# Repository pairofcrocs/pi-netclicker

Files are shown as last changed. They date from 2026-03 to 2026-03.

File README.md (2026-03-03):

# Pi NetClicker

A wireless, battery-powered button device that sends real mouse click events to a Windows PC over a network. Press a physical button on the handheld device — the PC receives a left mouse down/up event instantly.

Communication runs over [Tailscale](https://tailscale.com), so it works across any network without port forwarding.

---

## How It Works

```
[Physical Button] → [Pi Zero 2 W] → Tailscale VPN → [Windows PC] → Mouse Click
```

- `button_client.py` runs on the Pi. It monitors the button via GPIO interrupt and sends `DOWN`/`UP` events over TCP to the Windows machine.
- `windows.py` runs on Windows. It receives those events and simulates real left mouse button presses using `pynput`.
- `ap_server.py` runs on the Pi and creates a Wi-Fi hotspot that lets you add or change network credentials from any phone or laptop. It's triggered on demand by a double-press of the PiSugar2's built-in button — no SSH or keyboard required.

---

## Parts List

| Part | Link |
|---|---|
| Raspberry Pi Zero 2 W | [Amazon](https://www.amazon.com/dp/B09LH5SBPS) |
| PiSugar2 (battery board) | [Amazon](https://www.amazon.com/dp/B08D678XPR) |
| 2200mAh extended battery | [Amazon](https://www.amazon.com/dp/B0CTQ6VBB6) |
| Momentary push button | [Amazon](https://www.amazon.com/dp/B09V2L86DR) |
| 3D printed case | `case.stl` + `lid.stl` (in this repo) |

---

## 3D Printed Case

Four STL files are included:

| File | Qty | Description |
|---|-----|---|
| `case.stl` | 1 | Main enclosure body |
| `lid.stl` | 2 | Top and bottom lids — print twice and glue to seal |
| `button.stl` | 1 | Button cap that sits over the momentary push button |
| `switch.stl` | 1 | Switch actuator/cover |

After assembling the electronics inside, glue both lids in place to seal the enclosure.

> **Note:** The 3D printed case is the weakest part of this build. It can crack under hard drops. The electronics inside are fine — reprint and reassemble if needed.

Any FDM printer works. No specific settings required.

---

## Hardware Assembly

### Wiring the Button

The button connects directly to the Pi's GPIO header — no resistors needed (internal pull-up is enabled in firmware).

| Button leg | Pi Zero 2 W pin |
|---|---|
| Leg 1 | GPIO 17 (physical pin 11) |
| Leg 2 | GND (physical pin 9) |

### Attaching the PiSugar2

The PiSugar2 attaches to the back of the Pi Zero 2 W via spring-loaded pogo pins — no soldering required. Align the board, press it on, and secure it with the included screws.

### Installing the 2200mAh Battery

The PiSugar2 ships with a smaller default battery. To use the 2200mAh extended battery:

1. Carefully disconnect the default battery's JST connector from the PiSugar2 board.
2. Connect the 2200mAh battery's JST connector in its place.
3. After booting (see software setup), open the PiSugar2 web interface at `http://<pi-ip>:8421`.
4. Navigate to **Settings** and set the battery capacity to **2200 mAh** so the percentage display is accurate.

### Configuring the PiSugar2 Button (Wi-Fi Provisioning)

The PiSugar2 has its own physical button. Configure a double-press to trigger `ap_server.py` so you can change Wi-Fi credentials at any time without SSH:

1. Open the PiSugar2 web interface at `http://<pi-ip>:8421`
2. Go to **Settings → Button**
3. Set the **Double Tap** action to **Custom** and enter:
   ```
   sudo python3 /home/<your-username>/ap_server.py
   ```
4. Save the setting

From that point on, a double-press of the PiSugar2 button will bring up the `NetClicker` hotspot so you can reconfigure Wi-Fi without touching a terminal.

---

## Software Setup

### 1. Flash the Pi

Use [Raspberry Pi Imager](https://www.raspberrypi.com/software/) to flash **Raspberry Pi OS Lite (64-bit)** to a microSD card.

In the Imager's advanced settings (gear icon), configure:
- Hostname (e.g. `netclicker`)
- Enable SSH
- Set a username/password
- Optionally pre-configure your Wi-Fi here (skips the `ap_server.py` step)

### 2. Wi-Fi Setup via ap_server.py

`ap_server.py` creates a temporary Wi-Fi hotspot called **`NetClicker`** so you can add or change network credentials from any phone or laptop. It's used for both initial setup and changing networks later.

First, install NetworkManager on the Pi:

```bash
sudo apt update && sudo apt install -y network-manager python3
sudo systemctl stop wpa_supplicant
sudo systemctl disable wpa_supplicant
```

Copy `ap_server.py` to the Pi, then run it:

```bash
sudo python3 ap_server.py
```

Or, after completing the PiSugar2 button setup below, simply **double-press the PiSugar2 button** to start it automatically.

**To connect and configure:**

1. On your phone or laptop, connect to Wi-Fi network **`NetClicker`** (password: `netclicker`)
2. Open a browser and go to `http://10.42.0.1:8080`
3. Select your network and enter the password
4. Click **Add Connection** — the Pi saves the credentials and reboots

### 3. Install Tailscale on the Pi

SSH into the Pi after it connects to your network:

```bash
curl -fsSL https://tailscale.com/install.sh | sh
sudo tailscale up
```

Follow the authentication link printed in the terminal. Once authenticated, note the Pi's Tailscale IP:

```bash
tailscale ip -4
```

### 4. Install Tailscale on Windows

Download and install Tailscale from [tailscale.com/download](https://tailscale.com/download). Sign in with the same account used on the Pi. Both devices should appear in your Tailscale admin panel.

### 5. Configure the Client

On the Pi, edit `button_client.py` and update `WINDOWS_IP` with your Windows machine's Tailscale IP address:

```python
WINDOWS_IP = '100.x.x.x'  # your Windows Tailscale IP
```

Find your Windows Tailscale IP in the Tailscale system tray icon or at [login.tailscale.com](https://login.tailscale.com).

### 6. Install Pi Dependencies

```bash
pip3 install RPi.GPIO
```

> `RPi.GPIO` may already be installed on Raspberry Pi OS. If the script runs without error, you're good.

### 7. Auto-Start on Boot (systemd service)

Create a service file so `button_client.py` starts automatically when the Pi powers on:

```bash
sudo nano /etc/systemd/system/netclicker.service
```

Paste the following (adjust the path if you placed the script elsewhere):

```ini
[Unit]
Description=NetClicker Button Client
After=network-online.target tailscaled.service
Wants=network-online.target

[Service]
ExecStart=/usr/bin/python3 /home/<your-username>/button_client.py
Restart=always
RestartSec=5
User=<your-username>

[Install]
WantedBy=multi-user.target
```

Enable and start it:

```bash
sudo systemctl daemon-reload
sudo systemctl enable netclicker
sudo systemctl start netclicker
```

Check it's running:

```bash
sudo systemctl status netclicker
```

From this point on, powering on the device will automatically connect to the Windows server.

---

## Windows Setup

### Install Dependencies

```bash
pip install pynput sv-ttk
pip install py-window-styles  # optional: dark title bar on Windows 11
```

### Run the Server

```bash
python windows.py
```

The GUI will appear and the server starts automatically on port `5000`. When the Pi connects, the status indicator turns green. Press the physical button — you'll see the click events in the log (enable "Log click events" checkbox to see each DOWN/UP).

### Features

- **Log click events:** Toggle logging of individual DOWN/UP events in the Options panel. Off by default to keep the log clean at high click rates.

---

## File Reference

| File | Runs on | Purpose |
|---|---|---|
| `button_client.py` | Raspberry Pi | Reads button, sends events over TCP |
| `windows.py` | Windows PC | Receives events, simulates mouse clicks |
| `ap_server.py` | Raspberry Pi | One-time Wi-Fi provisioning hotspot |
| `case.stl` | — | 3D printable enclosure body |
| `lid.stl` | — | 3D printable lid (print twice) |
| `button.stl` | — | 3D printable button cap |
| `switch.stl` | — | 3D printable switch actuator |

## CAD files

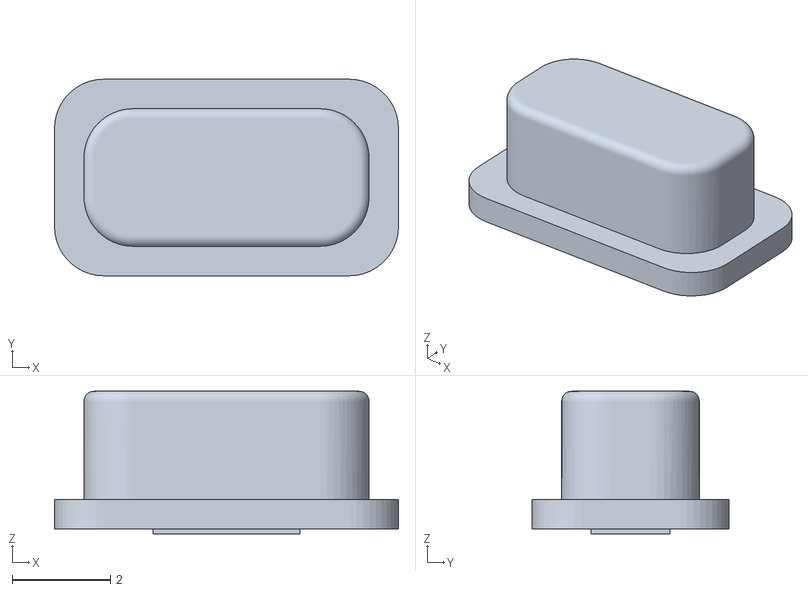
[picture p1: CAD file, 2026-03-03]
button.stl
7.00 x 4.00 x 2.90

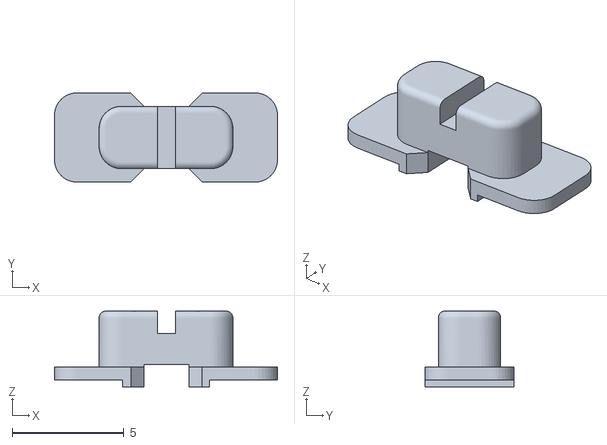
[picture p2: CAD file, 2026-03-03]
switch.stl
10.0 x 4.00 x 3.40

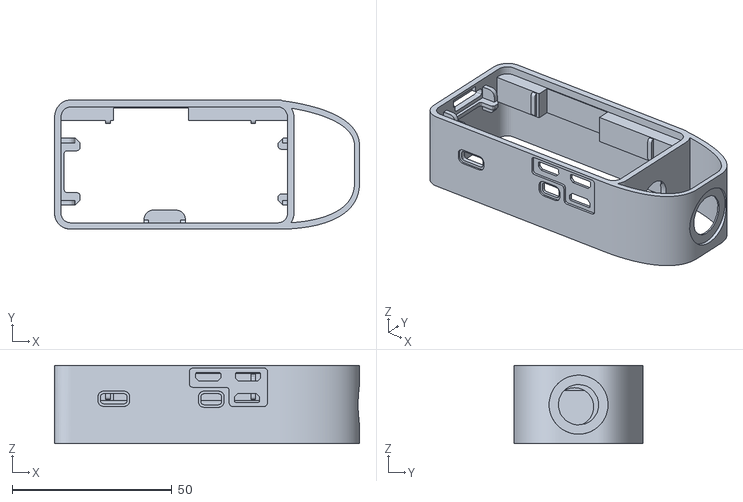
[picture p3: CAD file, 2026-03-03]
case.stl
95.5 x 40.5 x 24.5

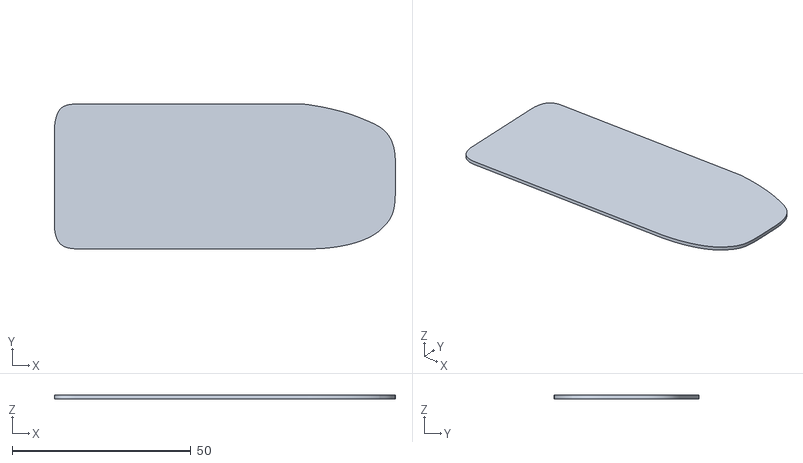
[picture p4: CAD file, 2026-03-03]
lid.stl
95.5 x 40.5 x 1.00

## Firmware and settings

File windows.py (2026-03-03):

#!/usr/bin/env python3
"""
Windows Click Server - GUI Version with Sun Valley Theme
Receives button events from Pi and simulates mouse clicks

IMPROVEMENTS:
- Better socket cleanup and handling
- Faster detection of dead connections
- TCP keepalive for detecting network changes
- Non-blocking client handling
"""

import select
import socket
import threading
import sys
import tkinter as tk
from tkinter import ttk
from datetime import datetime
from pynput.mouse import Button, Controller
import sv_ttk

# Optional: py-window-styles for dark title bar on Windows
try:
    import pywinstyles
    _HAS_PYWINSTYLES = True
except Exception:
    _HAS_PYWINSTYLES = False

LISTEN_IP = '0.0.0.0'
PORT = 5000


def apply_theme_to_titlebar(root):
    try:
        if not _HAS_PYWINSTYLES:
            return
        version = sys.getwindowsversion()
        dark_mode = sv_ttk.get_theme() == "dark"
        if version.major == 10 and version.build >= 22000:
            pywinstyles.change_header_color(root, "#1c1c1c" if dark_mode else "#fafafa")
        elif version.major == 10:
            pywinstyles.apply_style(root, "dark" if dark_mode else "normal")
            try:
                root.wm_attributes("-alpha", 0.99)
                root.wm_attributes("-alpha", 1.0)
            except tk.TclError:
                pass
    except Exception:
        pass


class ClickServerGUI:
    def __init__(self, root):
        self.root = root
        self.root.title("Windows Click Server")
        self.root.geometry("700x600")
        self.root.resizable(False, False)

        sv_ttk.set_theme("dark")
        self.root.bind("<Map>", lambda e: apply_theme_to_titlebar(self.root))

        self.server = None
        self.is_running = False
        self.mouse = Controller()
        self.client_connected = False
        
        # Track current client connection
        self.current_client_conn = None
        self.client_lock = threading.Lock()

        # --- Click logging toggle ---
        self.log_clicks_var = tk.BooleanVar(value=False)

        self.setup_ui()
        self.root.after(100, self.start_server)

    # --------------------------------------------------------
    def setup_ui(self):
        main_frame = ttk.Frame(self.root, padding="15")
        main_frame.grid(row=0, column=0, sticky=(tk.W, tk.E, tk.N, tk.S))

        title_label = ttk.Label(main_frame, text="Click Server", font=("Segoe UI", 18, "bold"))
        title_label.grid(row=0, column=0, columnspan=2, pady=(0, 15))

        # Status frame
        status_frame = ttk.LabelFrame(main_frame, text="Status", padding="15")
        status_frame.grid(row=1, column=0, columnspan=2, sticky=(tk.W, tk.E), pady=(0, 15))

        server_frame = ttk.Frame(status_frame)
        server_frame.grid(row=0, column=0, sticky=tk.W, pady=5)
        ttk.Label(server_frame, text="Server:", font=("Segoe UI", 10)).pack(side=tk.LEFT, padx=(0, 10))
        self.server_status = tk.Canvas(server_frame, width=12, height=12, highlightthickness=0, bg="#1c1c1c")
        self.server_status.pack(side=tk.LEFT, padx=(0, 8))
        self.server_indicator = self.server_status.create_oval(2, 2, 10, 10, fill="#6c6c6c", outline="")
        self.server_label = ttk.Label(server_frame, text="Stopped", font=("Segoe UI", 10))
        self.server_label.pack(side=tk.LEFT)

        client_frame = ttk.Frame(status_frame)
        client_frame.grid(row=1, column=0, sticky=tk.W, pady=5)
        ttk.Label(client_frame, text="Client:", font=("Segoe UI", 10)).pack(side=tk.LEFT, padx=(0, 10))
        self.client_status = tk.Canvas(client_frame, width=12, height=12, highlightthickness=0, bg="#1c1c1c")
        self.client_status.pack(side=tk.LEFT, padx=(0, 8))
        self.client_indicator = self.client_status.create_oval(2, 2, 10, 10, fill="#6c6c6c", outline="")
        self.client_label = ttk.Label(client_frame, text="Not Connected", font=("Segoe UI", 10))
        self.client_label.pack(side=tk.LEFT)

        address_frame = ttk.Frame(status_frame)
        address_frame.grid(row=2, column=0, sticky=tk.W, pady=5)
        ttk.Label(address_frame, text="Address:", font=("Segoe UI", 10)).pack(side=tk.LEFT, padx=(0, 10))
        self.address_label = ttk.Label(address_frame, text=f"{LISTEN_IP}:{PORT}", font=("Segoe UI", 10, "bold"), foreground="#0078d4")
        self.address_label.pack(side=tk.LEFT)

        # Buttons
        button_frame = ttk.Frame(main_frame)
        button_frame.grid(row=2, column=0, columnspan=2, pady=(0, 10))
        self.start_btn = ttk.Button(button_frame, text="Start Server", command=self.start_server, width=18)
        self.start_btn.grid(row=0, column=0, padx=5)
        self.stop_btn = ttk.Button(button_frame, text="Stop Server", command=self.stop_server, width=18, state=tk.DISABLED)
        self.stop_btn.grid(row=0, column=1, padx=5)
        self.clear_btn = ttk.Button(button_frame, text="Clear Log", command=self.clear_log, width=18)
        self.clear_btn.grid(row=0, column=2, padx=5)

        # --- Options frame ---
        options_frame = ttk.LabelFrame(main_frame, text="Options", padding="15")
        options_frame.grid(row=3, column=0, columnspan=2, sticky=(tk.W, tk.E), pady=(0, 15))

        self.log_clicks_chk = ttk.Checkbutton(
            options_frame,
            text="Log click events (DOWN/UP)",
            variable=self.log_clicks_var
        )
        self.log_clicks_chk.grid(row=0, column=0, sticky=tk.W)

        # Log frame
        log_frame = ttk.LabelFrame(main_frame, text="Activity Log", padding="15")
        log_frame.grid(row=4, column=0, columnspan=2, sticky=(tk.W, tk.E, tk.N, tk.S))
        log_frame.columnconfigure(0, weight=1)
        log_frame.rowconfigure(0, weight=1)
        self.log_text = tk.Text(
            log_frame, height=16, width=80, wrap=tk.WORD, font=("Consolas", 9),
            bg="#1e1e1e", fg="#d4d4d4", insertbackground="white",
            borderwidth=0, highlightthickness=0
        )
        self.log_scrollbar = ttk.Scrollbar(log_frame, orient="vertical", command=self.log_text.yview)
        self.log_text.configure(yscrollcommand=self.log_scrollbar.set)
        self.log_text.grid(row=0, column=0, sticky="nsew")
        self.log_scrollbar.grid(row=0, column=1, sticky="ns")

        self.log_text.tag_config("info", foreground="#d4d4d4")
        self.log_text.tag_config("success", foreground="#4ec9b0")
        self.log_text.tag_config("warning", foreground="#ce9178")
        self.log_text.tag_config("error", foreground="#f48771")
        self.log_text.tag_config("timestamp", foreground="#858585")

        self.root.columnconfigure(0, weight=1)
        self.root.rowconfigure(0, weight=1)
        main_frame.columnconfigure(0, weight=1)
        main_frame.rowconfigure(4, weight=1)

        if not _HAS_PYWINSTYLES:
            self.root.after(300, lambda: self.log(
                "Tip: Install 'py-window-styles' for dark title bar on Windows: pip install py-window-styles",
                "warning"
            ))

    def log(self, message, tag="info"):
        timestamp = datetime.now().strftime("%H:%M:%S")
        self.log_text.config(state=tk.NORMAL)
        self.log_text.insert(tk.END, f"[{timestamp}] ", "timestamp")
        self.log_text.insert(tk.END, f"{message}\n", tag)
        self.log_text.see(tk.END)
        self.log_text.config(state=tk.DISABLED)

    def clear_log(self):
        self.log_text.config(state=tk.NORMAL)
        self.log_text.delete(1.0, tk.END)
        self.log_text.config(state=tk.DISABLED)

    def update_server_status(self, running):
        if running:
            self.server_status.itemconfig(self.server_indicator, fill="#4ec9b0")
            self.server_label.config(text="Running")
            self.start_btn.config(state=tk.DISABLED)
            self.stop_btn.config(state=tk.NORMAL)
        else:
            self.server_status.itemconfig(self.server_indicator, fill="#6c6c6c")
            self.server_label.config(text="Stopped")
            self.start_btn.config(state=tk.NORMAL)
            self.stop_btn.config(state=tk.DISABLED)

    def update_client_status(self, connected, addr=None):
        self.client_connected = connected
        if connected:
            self.client_status.itemconfig(self.client_indicator, fill="#4ec9b0")
            self.client_label.config(text=f"Connected: {addr}")
        else:
            self.client_status.itemconfig(self.client_indicator, fill="#6c6c6c")
            self.client_label.config(text="Not Connected")

    def disconnect_current_client(self):
        """Safely disconnect the current client"""
        with self.client_lock:
            if self.current_client_conn:
                try:
                    self.current_client_conn.shutdown(socket.SHUT_RDWR)
                except:
                    pass
                try:
                    self.current_client_conn.close()
                except:
                    pass
                self.current_client_conn = None

    def handle_client(self, conn, addr):
        # Store the current connection
        with self.client_lock:
            # Disconnect any existing client first
            if self.current_client_conn:
                try:
                    self.current_client_conn.shutdown(socket.SHUT_RDWR)
                    self.current_client_conn.close()
                except:
                    pass
            self.current_client_conn = conn
        
        self.root.after(0, lambda: self.update_client_status(True, addr))
        self.root.after(0, lambda: self.log(f"Client connected from {addr}", "success"))
        
        buffer = ""

        try:
            while self.is_running:
                ready, _, _ = select.select([conn], [], [], 0.5)
                if not ready:
                    continue
                try:
                    data = conn.recv(1024)
                    if not data:
                        self.root.after(0, lambda: self.log("Client disconnected (clean)", "warning"))
                        break

                    buffer += data.decode()
                    while '\n' in buffer:
                        message, buffer = buffer.split('\n', 1)
                        message = message.strip()
                        if message == "DOWN":
                            self.mouse.press(Button.left)
                            if self.log_clicks_var.get():
                                self.root.after(0, lambda: self.log("Mouse DOWN", "info"))
                        elif message == "UP":
                            self.mouse.release(Button.left)
                            if self.log_clicks_var.get():
                                self.root.after(0, lambda: self.log("Mouse UP", "info"))
                except Exception as e:
                    self.root.after(0, lambda e=e: self.log(f"Client error: {e}", "error"))
                    break
        except Exception as e:
            self.root.after(0, lambda e=e: self.log(f"Error: {e}", "error"))
        finally:
            with self.client_lock:
                if self.current_client_conn == conn:
                    self.current_client_conn = None
            
            try:
                conn.shutdown(socket.SHUT_RDWR)
            except:
                pass
            try:
                conn.close()
            except:
                pass
            
            self.root.after(0, lambda: self.update_client_status(False))
            self.root.after(0, lambda: self.log("Connection closed", "info"))

    def server_thread(self):
        self.server = socket.socket(socket.AF_INET, socket.SOCK_STREAM)
        self.server.setsockopt(socket.SOL_SOCKET, socket.SO_REUSEADDR, 1)
        self.server.setsockopt(socket.SOL_SOCKET, socket.SO_KEEPALIVE, 1)
        
        # Enable TCP keepalive to detect dead connections faster
        if sys.platform == 'win32':
            # Windows: (on/off, time, interval)
            self.server.ioctl(socket.SIO_KEEPALIVE_VALS, (1, 10000, 3000))
        
        try:
            self.server.bind((LISTEN_IP, PORT))
            self.server.listen(1)
            self.server.settimeout(1.0)
            self.root.after(0, lambda: self.log(f"Server listening on {LISTEN_IP}:{PORT}", "success"))
            self.root.after(0, lambda: self.log("Waiting for Pi to connect...", "info"))
            
            while self.is_running:
                try:
                    conn, addr = self.server.accept()
                    
                    # Configure the client socket with keepalive
                    conn.setsockopt(socket.SOL_SOCKET, socket.SO_KEEPALIVE, 1)
                    if sys.platform == 'win32':
                        conn.ioctl(socket.SIO_KEEPALIVE_VALS, (1, 10000, 3000))
                    
                    # Handle client in a separate thread so we can continue accepting
                    client_thread = threading.Thread(
                        target=self.handle_client, 
                        args=(conn, addr), 
                        daemon=True
                    )
                    client_thread.start()
                    
                except socket.timeout:
                    continue
                except Exception as e:
                    if self.is_running:
                        self.root.after(0, lambda e=e: self.log(f"Accept error: {e}", "error"))
        except Exception as e:
            self.root.after(0, lambda e=e: self.log(f"Server error: {e}", "error"))
        finally:
            self.server.close()
            self.root.after(0, lambda: self.update_server_status(False))

    def start_server(self):
        if not self.is_running:
            self.is_running = True
            self.update_server_status(True)
            self.log("Starting server...", "info")
            thread = threading.Thread(target=self.server_thread, daemon=True)
            thread.start()

    def stop_server(self):
        if self.is_running:
            self.log("Stopping server...", "warning")
            self.is_running = False
            self.disconnect_current_client()
            self.update_client_status(False)

    def on_closing(self):
        self.is_running = False
        self.disconnect_current_client()
        if self.server:
            try:
                self.server.close()
            except Exception:
                pass
        self.root.destroy()


def main():
    root = tk.Tk()
    app = ClickServerGUI(root)
    root.update_idletasks()
    apply_theme_to_titlebar(root)
    root.protocol("WM_DELETE_WINDOW", app.on_closing)
    root.mainloop()


if __name__ == "__main__":
    main()

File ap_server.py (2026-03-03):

#!/usr/bin/env python3
import os
import sys
import subprocess
from http.server import HTTPServer, BaseHTTPRequestHandler
from urllib.parse import parse_qs
import threading
import json
import time
import shlex

# ====== Config ======
HOTSPOT_SSID = "NetClicker"
HOTSPOT_PASS = "netclicker"   # >= 8 chars
HOTSPOT_CON_NAME = "NetClickerHotspot"
WIFI_CON_NAME_PREFIX = "WiFi-"
WIFI_IFACE = "wlan0"

# Priority hints (higher wins). Keep hotspot very low just in case.
NEW_WIFI_PRIORITY = 10
HOTSPOT_PRIORITY = -999

# ====== Helpers ======
def run(cmd, check=True, capture=True):
    if isinstance(cmd, str):
        cmd_list = shlex.split(cmd)
    else:
        cmd_list = cmd
    result = subprocess.run(
        cmd_list,
        stdout=subprocess.PIPE if capture else None,
        stderr=subprocess.STDOUT,
        text=True,
    )
    if check and result.returncode != 0:
        raise RuntimeError(f"Command failed: {cmd}\nOutput:\n{result.stdout}")
    return result.stdout.strip() if capture else ""

def nm_available():
    try:
        run("nmcli -v")
        return True
    except Exception:
        return False

def ensure_root():
    if os.geteuid() != 0:
        print("Please run as root: sudo python3 pi_wifi_setup.py")
        sys.exit(1)

def get_ip_for_iface(iface):
    try:
        out = run(f"ip -4 addr show {iface}")
        for line in out.splitlines():
            line = line.strip()
            if line.startswith("inet "):
                return line.split()[1].split("/")[0]
    except Exception:
        pass
    return None

def delete_connection_if_exists(name):
    try:
        conns = run("nmcli -t -f NAME connection show")
        for c in conns.splitlines():
            if c.strip() == name:
                run(f"nmcli connection delete {shlex.quote(name)}")
                break
    except Exception:
        pass

# ====== Hotspot control (never autoconnect) ======
def start_hotspot():
    """Create/bring up a deterministic NM hotspot on WIFI_IFACE; autoconnect is disabled."""
    # Clean any auto "Hotspot" profile & our named one
    delete_connection_if_exists("Hotspot")
    delete_connection_if_exists(HOTSPOT_CON_NAME)

    # Create AP profile with AUTOCONNECT DISABLED
    run(
        f"nmcli connection add type wifi ifname {WIFI_IFACE} con-name {HOTSPOT_CON_NAME} "
        f"ssid {HOTSPOT_SSID}"
    )
    run(f"nmcli connection modify {HOTSPOT_CON_NAME} connection.autoconnect no")
    run(f"nmcli connection modify {HOTSPOT_CON_NAME} connection.autoconnect-priority {HOTSPOT_PRIORITY}")

    # AP settings
    run(f"nmcli connection modify {HOTSPOT_CON_NAME} 802-11-wireless.mode ap")
    run(f"nmcli connection modify {HOTSPOT_CON_NAME} 802-11-wireless.band bg")
    run(f"nmcli connection modify {HOTSPOT_CON_NAME} 802-11-wireless.channel 1")
    run(f"nmcli connection modify {HOTSPOT_CON_NAME} 802-11-wireless.hidden no")
    run(f"nmcli connection modify {HOTSPOT_CON_NAME} 802-11-wireless.powersave 2")

    # WPA2-PSK
    run(f"nmcli connection modify {HOTSPOT_CON_NAME} wifi-sec.key-mgmt wpa-psk")
    run(f"nmcli connection modify {HOTSPOT_CON_NAME} wifi-sec.psk {HOTSPOT_PASS}")

    # IP sharing for captive-style access
    run(f"nmcli connection modify {HOTSPOT_CON_NAME} ipv4.method shared")
    run(f"nmcli connection modify {HOTSPOT_CON_NAME} ipv6.method ignore")

    # Explicitly bring it up (since autoconnect is OFF)
    run(f"nmcli connection up {HOTSPOT_CON_NAME}")

    # Wait for IP (commonly 10.42.0.1)
    for _ in range(30):
        ip = get_ip_for_iface(WIFI_IFACE)
        if ip:
            return ip
        time.sleep(0.3)
    return get_ip_for_iface(WIFI_IFACE)

def stop_hotspot():
    try:
        run(f"nmcli connection down {HOTSPOT_CON_NAME}", check=False)
        # Keep the profile, but with autoconnect disabled it won't start at boot.
        # If you prefer, delete it instead:
        # delete_connection_if_exists(HOTSPOT_CON_NAME)
    except Exception:
        pass

def scan_ssids():
    try:
        run(f"nmcli dev wifi rescan ifname {WIFI_IFACE}", check=False)
        out = run(f"nmcli -t -f SSID dev wifi list ifname {WIFI_IFACE}")
        ssids = []
        for line in out.splitlines():
            s = line.strip()
            if s and s not in ssids:
                ssids.append(s)
        return [s for s in ssids if s]
    except Exception:
        return []

def get_saved_wifi_connections():
    """Get list of saved Wi-Fi connections with their SSIDs and passwords."""
    try:
        # Get all connection names that match our prefix
        out = run("nmcli -t -f NAME connection show")
        saved = []
        for line in out.splitlines():
            name = line.strip()
            if name.startswith(WIFI_CON_NAME_PREFIX):
                ssid = name[len(WIFI_CON_NAME_PREFIX):]
                # Try to get the password
                try:
                    psk_out = run(f"nmcli -s -g 802-11-wireless-security.psk connection show {shlex.quote(name)}")
                    psk = psk_out.strip() if psk_out else None
                except:
                    psk = None
                saved.append({"name": name, "ssid": ssid, "psk": psk})
        return saved
    except Exception:
        return []

def delete_saved_connection(con_name):
    """Delete a saved Wi-Fi connection."""
    try:
        run(f"nmcli connection delete {shlex.quote(con_name)}")
        return True
    except Exception:
        return False

# ====== Wi-Fi provisioning (no immediate connect) ======
def add_wifi_profile_only(ssid, psk=None):
    con_name = f"{WIFI_CON_NAME_PREFIX}{ssid}"
    delete_connection_if_exists(con_name)

    run(
        f"nmcli connection add type wifi ifname {WIFI_IFACE} "
        f"con-name {shlex.quote(con_name)} ssid {shlex.quote(ssid)}"
    )
    run(f"nmcli connection modify {shlex.quote(con_name)} connection.autoconnect yes")
    run(f"nmcli connection modify {shlex.quote(con_name)} connection.autoconnect-priority  {NEW_WIFI_PRIORITY}")

    if psk:
        run(f"nmcli connection modify {shlex.quote(con_name)} wifi-sec.key-mgmt wpa-psk")
        run(f"nmcli connection modify {shlex.quote(con_name)} wifi-sec.psk {shlex.quote(psk)}")
    else:
        run(f"nmcli connection modify {shlex.quote(con_name)} wifi-sec.key-mgmt none")

    # Do NOT bring it up now
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

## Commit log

2026-03-03 Initial commit: Pi NetClicker
    [case.stl, lid.stl]
2026-03-03 Add button and switch STLs, update README with full parts list
    [button.stl, switch.stl]
